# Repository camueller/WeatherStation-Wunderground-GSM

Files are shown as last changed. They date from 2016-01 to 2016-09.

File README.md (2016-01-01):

Deutsche Seite

GSM based weather station for the Weather Underground Network
======
Currently full description is only available in German using the link above.

I'm running this weather station on our paramotor airfield.

### Hardware:
- [Arduino UNO](https://www.arduino.cc/en/Main/ArduinoBoardUno)
- [EFCom_GPRS/GSM_Shield](http://www.elecfreaks.com/wiki/index.php?title=EFCom_GPRS/GSM_Shield)

### Sensors:
- wind speed (from WH1080)
- wind direction (from WH1080)
- temperature (Maxim DS18B20)
- humidity (Honeywell HIH-5031)
- pressure (Freescale MPL3115A2)
- rain gauge (from WH1080)
- solar radiation (8x BPW34)

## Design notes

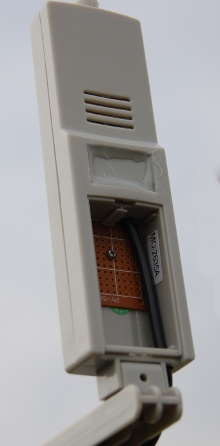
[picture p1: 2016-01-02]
pics/StevensonScreenGehaeuseOffen.JPG

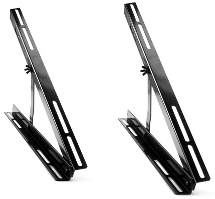
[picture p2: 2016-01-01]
pics/SolarmodulHalterung.png

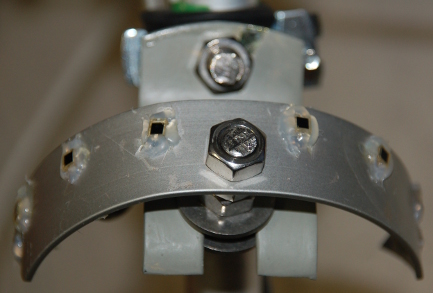
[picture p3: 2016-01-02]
pics/Pyranometer.JPG

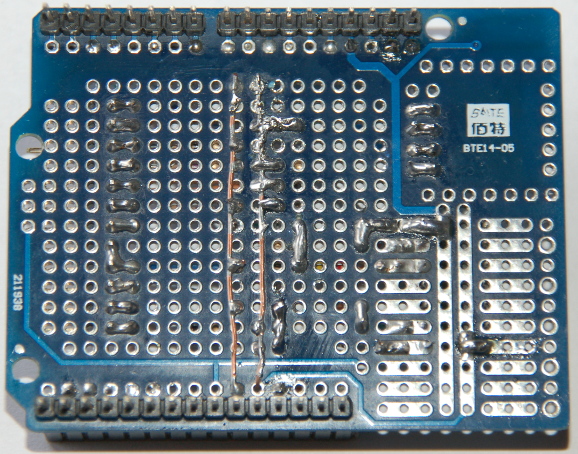
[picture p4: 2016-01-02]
pics/ProtoShieldVonUnten.JPG

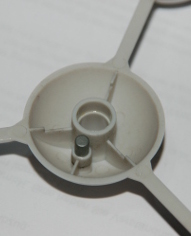
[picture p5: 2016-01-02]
pics/WindmesserVonUnten.JPG

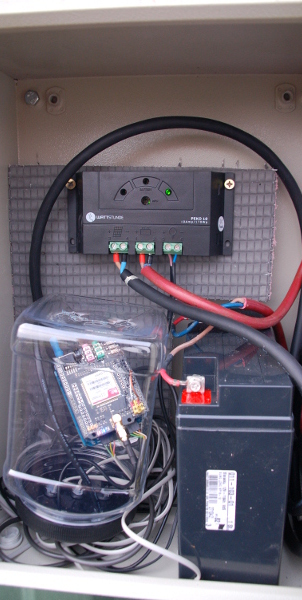
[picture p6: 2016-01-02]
pics/Schaltschrank.JPG

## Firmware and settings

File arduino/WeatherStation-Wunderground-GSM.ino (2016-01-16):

/*
 This Arduino sketch controls a personal weather station and uses a GSM shield to upload data to wunderground.com.
 For updates check https://github.com/camueller/WeatherStation-Wunderground-GSM
 */

//////////////
// Libraries
//////////////

#include <avr/wdt.h>

//////////////
// Variables
//////////////

//#define INFO_WS 1    // INFO is already defined in LOG.h of GSM GPRS shield
//#define DEBUG_WS 1   // DEBUG is already defined in LOG.h of GSM GPRS shield
//#define DEBUG_UPLOAD 1
#define UPLOAD 1

#define ENABLE_TEMPERATURE 1
#define ENABLE_WIND_SPEED 1
#define ENABLE_WIND_DIRECTION 1
#define ENABLE_RAIN 1
#define ENABLE_SOLAR_RADIATION 1
#define ENABLE_HUMIDITY 1
#define ENABLE_PRESSURE 1

#define WDT_COUNTER_MAX 40  // 40=320s : Number of times of ISR(WDT_vect) to autoreset the board. I will autoreset the board after 8 secondes x counterMax
volatile int wdtCounter; 

unsigned const long MAX_LONG = 4294967295;
unsigned const int ANALOG_READINGS = 100;
unsigned int hourOfDay = -1;

// results
unsigned int   humidity;
float          temperature;
float          dewpoint;
         float windSpeed;
         float windSpeedAvg;
         float windSpeedGust;
unsigned int   windDirection;
unsigned int   windDirectionAvg;
unsigned int   windGustDirection;
         float rainLastHour;
         float rainToday;
unsigned int   solarRadiation;
         float pressure;

//////////////
// Pins set up
//////////////

// analog input
unsigned const int unusedAnalogPin   = A0;
unsigned const int windDirectionPin  = A2;
unsigned const int solarRadiationPin = A3;
unsigned const int humidityPin       = A4;

// digital
unsigned const int windSpeedInterrupt= 0; // D2
unsigned const int rainInterrupt     = 1; // D3
unsigned const int temperaturePin    = 7;
unsigned const int gsmPin            = 6;

//////////////
// Watchdog
// http://www.seeedstudio.com/recipe/279-long-time-auto-reset-feature-for-your-arduino.html
//////////////

ISR (WDT_vect)
{
        wdtCounter += 1;
        if (wdtCounter < WDT_COUNTER_MAX - 1) {
            wdt_reset(); // Reset timer, still in interrupt mode       
                         // Next time watchdogtimer complete the cicle, it will generate antoher ISR interrupt
        } else {
            MCUSR = 0;
            WDTCSR |= 0b00011000;    //WDCE y WDE = 1 --> config mode
            WDTCSR = 0b00001000 | 0b100001;    //clear WDIE (interrupt mode disabled), set WDE (reset mode enabled) and set interval to 8 seconds
                                               //Next time watchdog timer complete the cicly will reset the IC
        }
}

void wdt_long_enable()
{
    wdtCounter = 0;
    cli();    //disabled ints
    MCUSR = 0;   //clear reset status
    WDTCSR |= 0b00011000;    //WDCE y WDE = 1 --> config mode
    WDTCSR = 0b01000000 | 0b100001;    //set WDIE (interrupt mode enabled), clear WDE (reset mode disabled) and set interval to 8 seconds
    sei();   //enable ints
}

void wdt_long_disable()
{
    wdt_disable();
}

//////////////
// Set up
//////////////
void setup() {
#ifdef DEBUG_WS
  setupLogging();
#elif INFO_WS
  setupLogging();
#endif

  wdt_disable();
  
  unsigned long now = currentMillis();
#ifdef ENABLE_TEMPERATURE
  setupTemperature();
#endif
#ifdef ENABLE_WIND_SPEED
  setupWindSpeed(now);
#endif
#ifdef ENABLE_WIND_DIRECTION
  setupWindDirection();
#endif
#ifdef ENABLE_RAIN
  setupRain(now);
#endif
#ifdef ENABLE_SOLAR_RADIATION
  setupSolarRadiation();
#endif
#ifdef ENABLE_HUMIDITY
  setupHumidity();
#endif
#ifdef ENABLE_PRESSURE
  setupPressure();
#endif

#ifdef UPLOAD
  setupUpload(now);
#endif
}

void setupLogging() {
  Serial.begin(9600);
  while (!Serial) {
    ; // wait for serial port to connect. Needed for Leonardo only
  }
}

//////////////
// Loop
//////////////

void loop() {

  wdt_long_enable();
  
  unsigned long now = currentMillis();
#ifdef INFO_WS
  Serial.print(F("\nnow="));Serial.print(now);Serial.print(F("\tfree="));Serial.println(freeRam());
#endif

#ifdef ENABLE_TEMPERATURE
  loopTemperature();
#endif
#ifdef ENABLE_WIND_SPEED
  loopWindSpeed(now);
#endif
#ifdef ENABLE_WIND_DIRECTION
  loopWindDirection(now);
#endif
#ifdef ENABLE_RAIN
  loopRain(now);
#endif
#ifdef ENABLE_SOLAR_RADIATION
  loopSolarRadiation();
#endif
#ifdef ENABLE_HUMIDITY
  loopHumidity();
#endif
#ifdef ENABLE_PRESSURE
  loopPressure();
#endif

#ifdef UPLOAD
  loopUpload(now);
#endif

  delay(1000);

  wdt_long_disable();
}

//////////////
// Functions
//////////////

/*
 * The sensors are connected to the Arduino with long wires that act as antennas and pick up noise. This caused the analog readings to fluctuate.
 * A first step towards repressing this noise could be to do 100 A/D conversions and taking the average. While this is a very straight forward approach, 
 * there are better options.
 * A median filter is much better in reducing the impact of noise than an averaging filter. It works like this: you take 100 measurements,
 * sort them from small to large and take the middle one. A median filter is much less influenced by outliers, since they end up at the beginning or the end.
 * A mode filter is a combination of a median filter and an averaging filter: you sort the values and take the average of the ones in the middle. 
 * In my case I take the average of the 10 center values.
 * 
 * Source: http://www.elcojacobs.com/eleminating-noise-from-sensor-readings-on-arduino-with-digital-filtering/
 * 
 * Note: this method takes 18 ms for 100 readings additional to the initial delay after reading the unusedAnalogPin
 */
int analogReadSmoothed(int pin){
  analogRead(unusedAnalogPin); // dummy read to discharge ADC
  delay(20); // wait a little
  // read multiple values and sort them to take the mode
  int sortedValues[ANALOG_READINGS];
  for(int i=0;i<ANALOG_READINGS;i++){
    int value = analogRead(pin);
    int j;
    if(value<sortedValues[0] || i==0){
       j=0; //insert at first position
    }
    else {
      for(j=1;j<i;j++) {
         if(sortedValues[j-1]<=value && sortedValues[j]>=value){
           // j is insert position
           break;
         }
      }
    }
    for(int k=i;k>j;k--){
      // move all values higher than current reading up one position
      sortedValues[k]=sortedValues[k-1];
    }
    sortedValues[j]=value; //insert current reading
  }
  //return scaled mode of 10 values
  float returnval = 0;
  for(int i=ANALOG_READINGS/2-5;i<(ANALOG_READINGS/2+5);i++){
    returnval +=sortedValues[i];
  }
  return returnval/10;
}

long currentMillis() {
#ifdef DEBUG_WS  
  return MAX_LONG - 10000 + millis();
#endif  
  return millis();
}

int freeRam () 
{
  extern int __heap_start, *__brkval; 
  int v; 
  return (int) &v - (__brkval == 0 ? (int) &__heap_start : (int) __brkval); 
}

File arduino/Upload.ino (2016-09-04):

/*
 This Arduino sketch controls a personal weather station and uses a GSM shield to upload data to wunderground.com.
 For updates check https://github.com/camueller/WeatherStation-Wunderground-GSM
 */

//////////////
// Libraries
//////////////

#include "SIM900.h"
#include <SoftwareSerial.h>
#include "inetGSM.h"
#include <avr/pgmspace.h>

//////////////
// Variables
//////////////

const          char    GET[] PROGMEM             = "GET ";
const          char    PATH1[] PROGMEM           = "/weatherstation";
const          char    PATH2[] PROGMEM           = "/updateweatherstation.php?";
// The line below containing the correct value is contained in a Credentials.ino
//const          char    ID[] PROGMEM              = "ID=IABCDEF";
// The line below containing the correct value is contained in a Credentials.ino
//const          char    PASSWORD[] PROGMEM        = "&PASSWORD=AbcDef";
const          char    DATE[] PROGMEM            = "&dateutc=now";
const          char    TEMP[] PROGMEM            = "&tempf=";
const          char    HUMIDITY[] PROGMEM        = "&humidity=";
const          char    DEWPT[] PROGMEM           = "&dewptf=";
const          char    WINDDIR[] PROGMEM         = "&winddir=";
const          char    WINDDIR_AVG2M[] PROGMEM   = "&winddir_avg2m=";
const          char    WINDGUSTDIR[] PROGMEM     = "&windgustdir=";
const          char    WINDSPEED[] PROGMEM       = "&windspeedmph=";
const          char    WINDSPEED_AVG2M[] PROGMEM = "&windspdmph_avg2m=";
const          char    WINDGUST[] PROGMEM        = "&windgustmph=";
const          char    WINDGUST_10M[] PROGMEM    = "&windgustmph_10m=";
const          char    BAROM[] PROGMEM           = "&baromin=";
const          char    RAIN[] PROGMEM            = "&rainin=";
const          char    RAIN_DAILY[] PROGMEM      = "&dailyrainin=";
const          char    SOLARRADIATION[] PROGMEM  = "&solarradiation=";
const          char    PRESSURE[] PROGMEM        = "&baromin=";
const          char    UPDATERAW[] PROGMEM       = "&action=updateraw";
const          char    HTTP_HOST[] PROGMEM       = " HTTP/1.0\r\nHost: ";
const          char    SERVER[] PROGMEM          = "weatherstation.wunderground.com";
const          char    USER_AGENT[] PROGMEM      = "\r\nUser-Agent: Arduino\r\n\r\n";

const          char* const path[] PROGMEM = { GET,             // 0
                                              PATH1,           // 1
                                              PATH2,           // 2
                                              ID,              // 3 
                                              PASSWORD,        // 4
                                              DATE,            // 5
                                              TEMP,            // 6
                                              HUMIDITY,        // 7
                                              DEWPT,           // 8
                                              WINDDIR,         // 9 
                                              WINDDIR_AVG2M,   // 10
                                              WINDGUSTDIR,     // 11
                                              WINDSPEED,       // 12
                                              WINDSPEED_AVG2M, // 13
                                              WINDGUST,        // 14
                                              WINDGUST_10M,    // 15
                                              BAROM,           // 16
                                              RAIN,            // 17
                                              RAIN_DAILY,      // 18
                                              SOLARRADIATION,  // 19
                                              PRESSURE,        // 20
                                              UPDATERAW,       // 21
                                              HTTP_HOST,       // 22
                                              SERVER,          // 23
                                              USER_AGENT       // 24
                                            };

const unsigned long    UPLOAD_INTERVAL_SECONDS = 300;
const unsigned int     GMT_OFFSET              = 1;
unsigned       long    upoadIntervalBegin;
InetGSM inet;

//////////////
// Set up
//////////////

void setupUpload(unsigned long now) {
#ifdef DEBUG_WS  
    Serial.println(F("setupUpload"));
#endif
  upoadIntervalBegin = now;
  turnOffGsm();
}

//////////////
// Loop
//////////////

void loopUpload(unsigned long now) {
  if(now - upoadIntervalBegin > 1000 * UPLOAD_INTERVAL_SECONDS) {
//  if(1 == 1) {
    turnOnGsm();
    
    //Start configuration of shield with baudrate.
    //For http uses is raccomanded to use 4800 or slower.
    boolean started;
    if (gsm.begin(9600)) {
      Serial.println(F("\nstatus=READY"));
      started=true;
    }
    else Serial.println(F("\nstatus=IDLE"));
  
    if(started){
      //GPRS attach, put in order APN, username and password.
      //If no needed auth let them blank.
      int attached = inet.attachGPRS("internet.telekom", "tm", "tm");
#ifdef DEBUG_UPLOAD
      if (attached)
        Serial.println(F("status=ATTACHED"));
      else
        Serial.println(F("status=ERROR"));
#endif
      delay(1000);

      //Read IP address.
      gsm.SimpleWriteln("AT+CIFSR");
      delay(5000);
      //Read until serial buffer is empty.
      gsm.WhileSimpleRead();

      const int dummyLen = 150;
      char dummy[dummyLen];
      if(httpGET(dummy, dummyLen) >= 0) {
#ifdef DEBUG_UPLOAD
        Serial.println(F("Analyzing response"));
#endif  
        
        // HTTP/1.0 200 OK
        // Content-Type: text/html
        // Date: Sat, 25 Apr 2015 06:00:00 GMT
        // Content-Length: 8
        // Connection: close
        //
        // success
        
        byte status = gsm.WaitResp(10000, 2000); 
        if (status == RX_FINISHED) {
#ifdef DEBUG_UPLOAD
          Serial.println(F("Response availabe in comm buffer"));
#endif
          char searchFor[4 + 1];
          for(int i=0;i<24;i++) {
            sprintf(searchFor," %02d:",i);
            if(gsm.IsStringReceived(searchFor)) {
              hourOfDay = (i + GMT_OFFSET) % 24; // +1 : we are GMT+1 in winter and ignore DST
            }    
          }
        }
#ifdef DEBUG_UPLOAD
        Serial.print(F("hourOfDay="));Serial.println(hourOfDay);
#endif  
      }
    }
      
    turnOffGsm();
    
    upoadIntervalBegin = now;
  }

  // uploading may take up to 40 seconds, therefore we have to ignore
  // the count increase during that time; otherwise we will see very 
  // high wind speed because of that wrong count increase
  initWindSpeedSignalCount();
}

void turnOnGsm() {
#ifdef DEBUG_UPLOAD
      Serial.println(F("Turn on GSM"));
#endif	
  digitalWrite(gsmPin, HIGH);
  delay(2500);
  digitalWrite(gsmPin, LOW);
  delay(2500);
}
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

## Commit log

2015-10-18 sensors added
2015-10-25 prepared for pressure sensor
2015-10-31 multiple analogRead/median filter/using Arduino Uno
2015-12-06 pressure sensor added
2016-01-01 Reread pressure if 0 is returned
2016-01-02 moved ino files to arduino folder
2016-01-16 ignoring link to arduino directory
